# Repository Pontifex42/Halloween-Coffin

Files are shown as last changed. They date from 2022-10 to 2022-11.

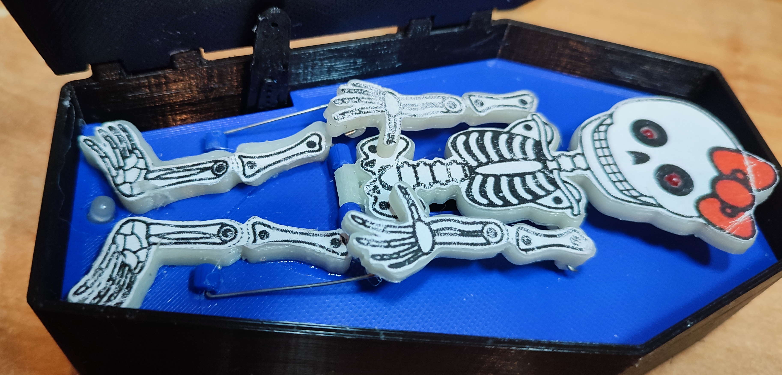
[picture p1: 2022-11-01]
Media/TopView.jpg

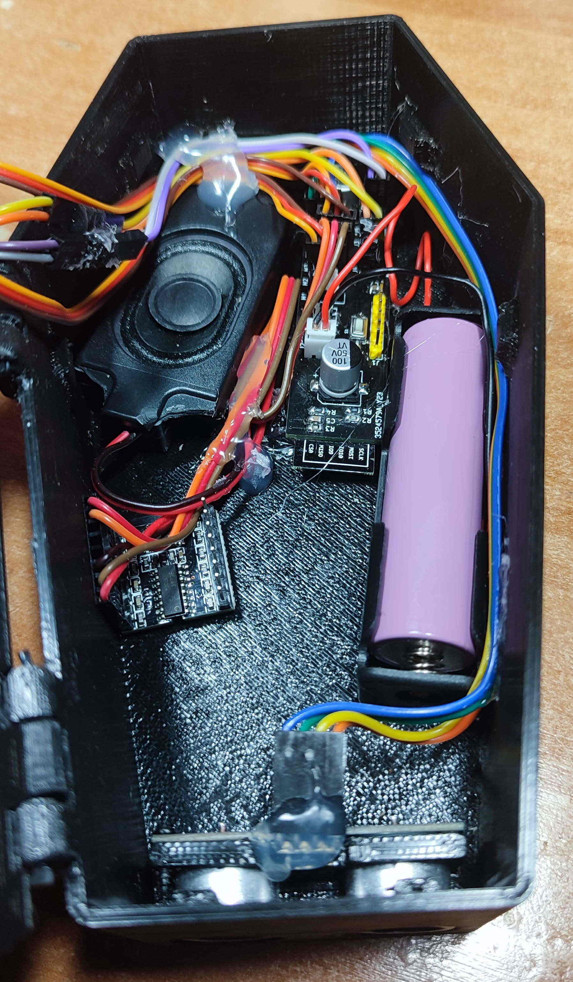
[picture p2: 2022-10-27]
Media/InnerView.jpg

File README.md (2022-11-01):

# Halloween-Coffin
A little scary toy.

Based on an idea from here:
https://www.az-delivery.de/blogs/azdelivery-blog-fur-arduino-und-raspberry-pi/halloween-2022-der-suessigkeitenwaechter

Software is based on a miniature board using ESP8266 which I developed myself.
Any other microcontroller would do, but my code might use some minor changes.
To make your own board, here are schematics and Gerber files:
https://github.com/Pontifex42/UniMiniESP8266
Not all components have to be populated, many parts are optional.

Some more information to build it is on thingiverse:
https://www.thingiverse.com/thing:5584885

Mp3 samples are for mp3 player like DFPlayer.
Some mp3 snippets are omitted due to legal reasons, I took them from a song "Nina Hagen - Auf'm Friedhof".
Feel free to place your own samples (< 10 seconds), the filename scheme is obvious.

Questions? Ideas? Contact github@hartwig.org. I answer all messages fast.

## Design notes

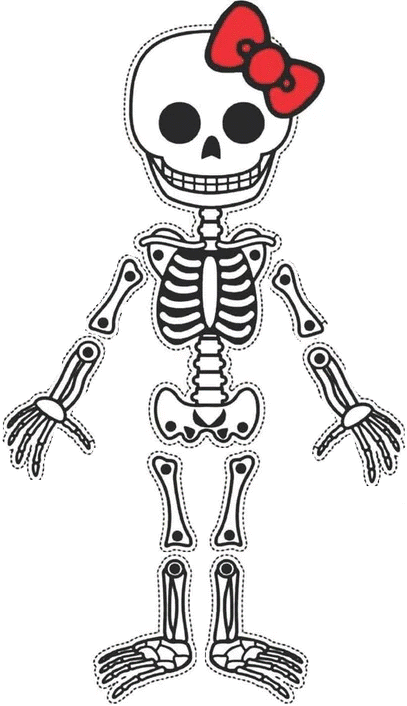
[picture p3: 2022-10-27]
Media/Skeleton_1024x1024.png

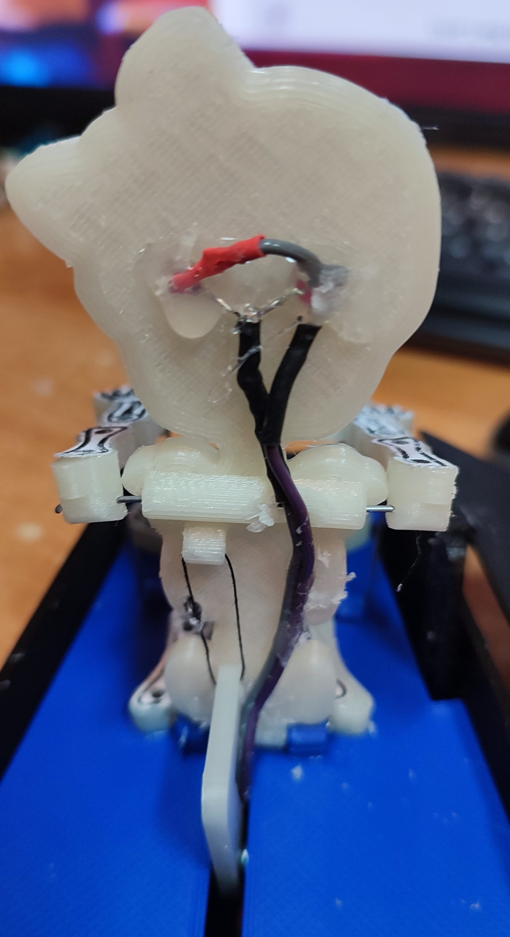
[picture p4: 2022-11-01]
Media/BackView.jpg

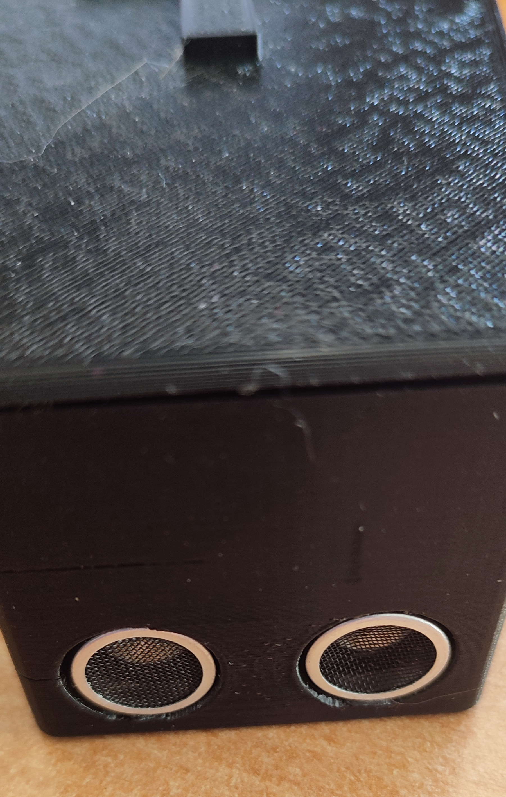
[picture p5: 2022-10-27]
Media/UltrasonicView.jpg

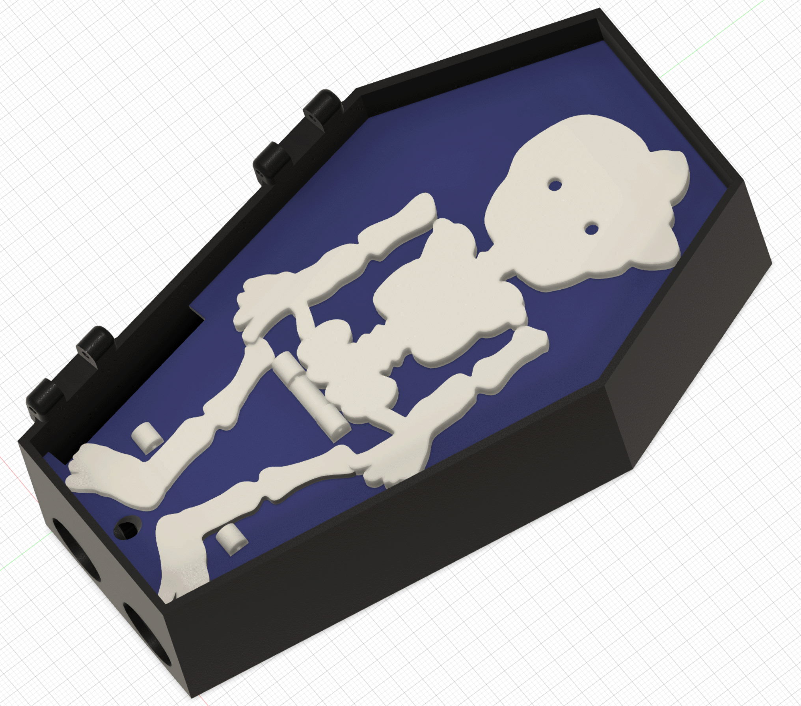
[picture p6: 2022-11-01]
Media/FusionView.jpg

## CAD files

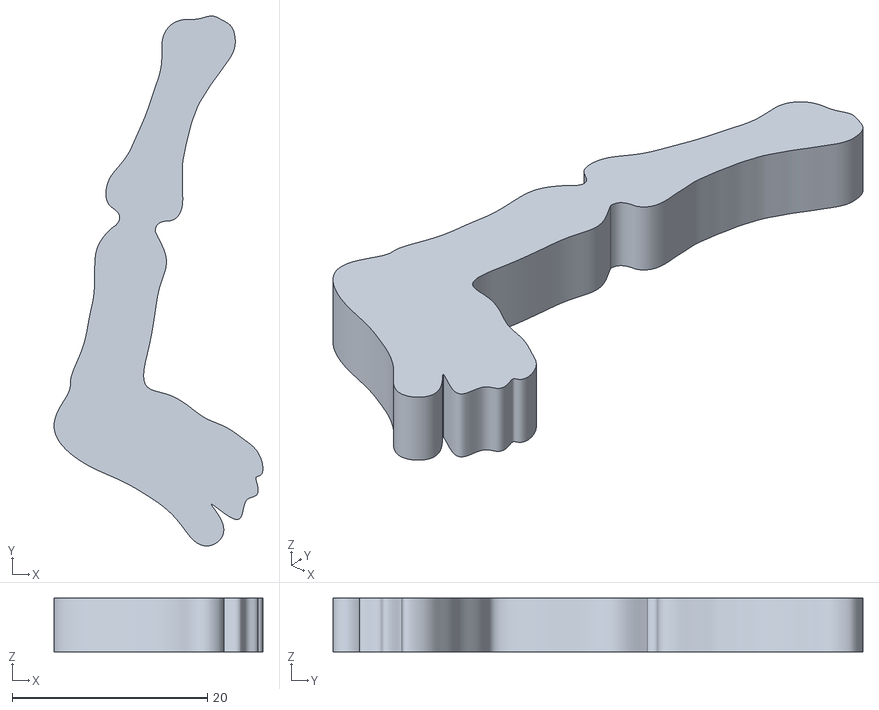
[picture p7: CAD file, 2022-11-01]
STL/Corpse Leg L.stl
21.4 x 54.3 x 5.50

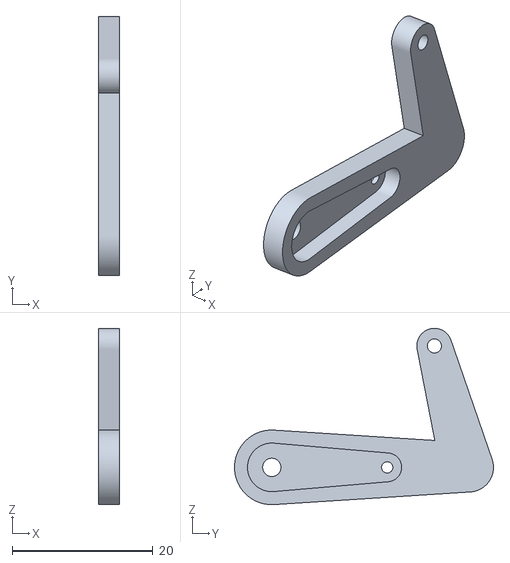
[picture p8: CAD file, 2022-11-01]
STL/Lever Short.stl
3.00 x 36.8 x 25.1

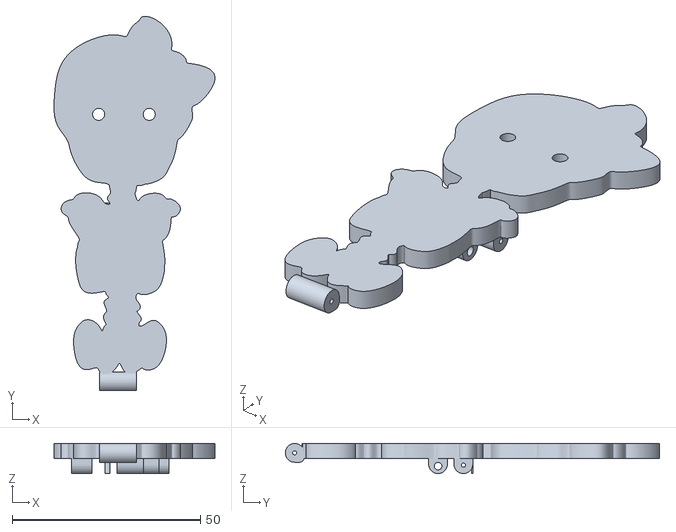
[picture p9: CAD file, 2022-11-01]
STL/Corpse Body.stl
42.7 x 99.4 x 8.00

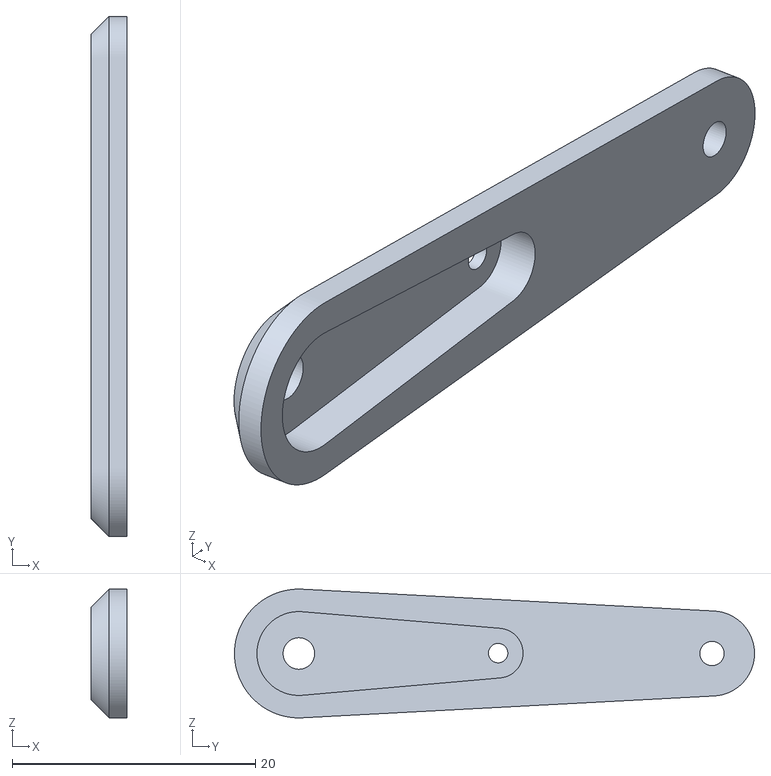
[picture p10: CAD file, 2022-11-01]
STL/Lever Long.stl
3.00 x 42.8 x 10.6

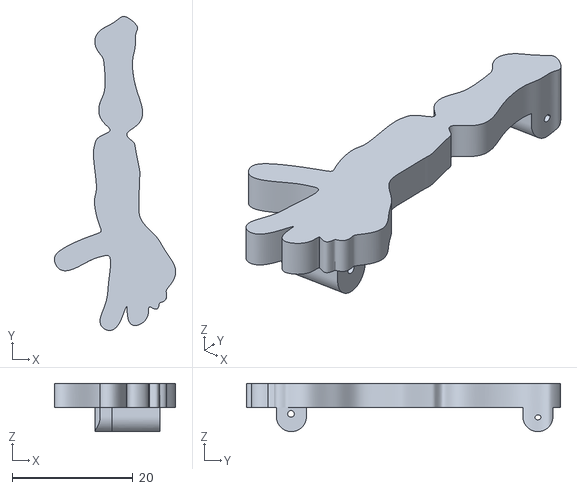
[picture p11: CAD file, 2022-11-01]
STL/Corpse Arm L.stl
20.1 x 52.1 x 8.00

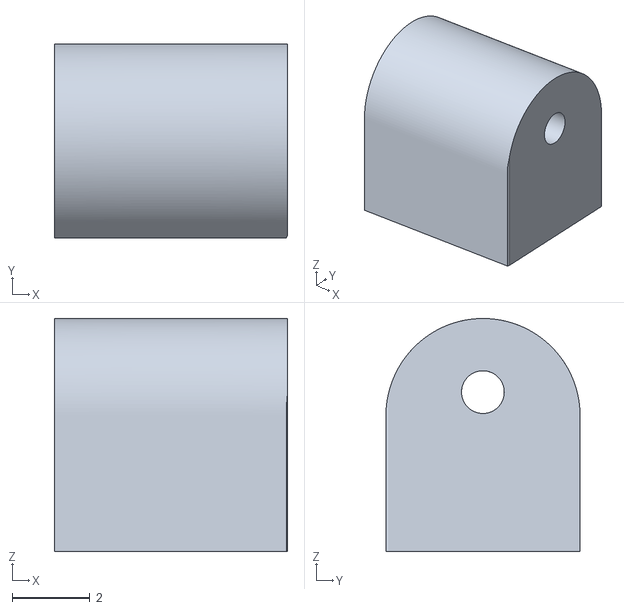
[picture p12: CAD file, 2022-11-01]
STL/Pelvis Hinge L.stl
6.00 x 5.00 x 6.00

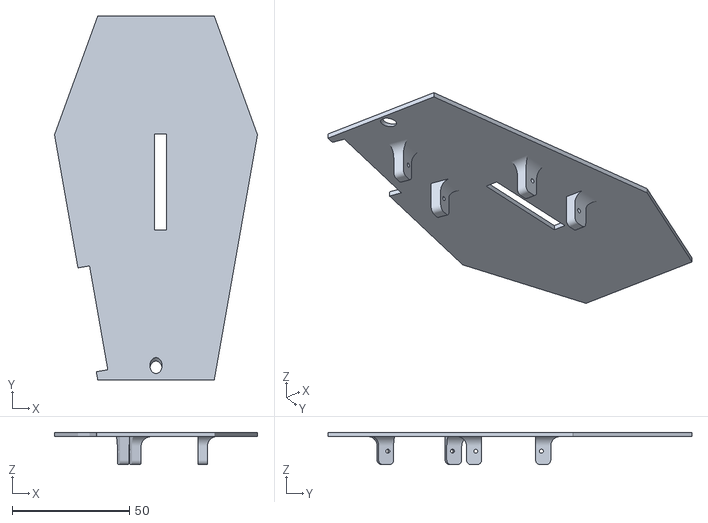
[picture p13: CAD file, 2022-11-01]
STL/InnerBoard.stl
86.6 x 155.2 x 13.8

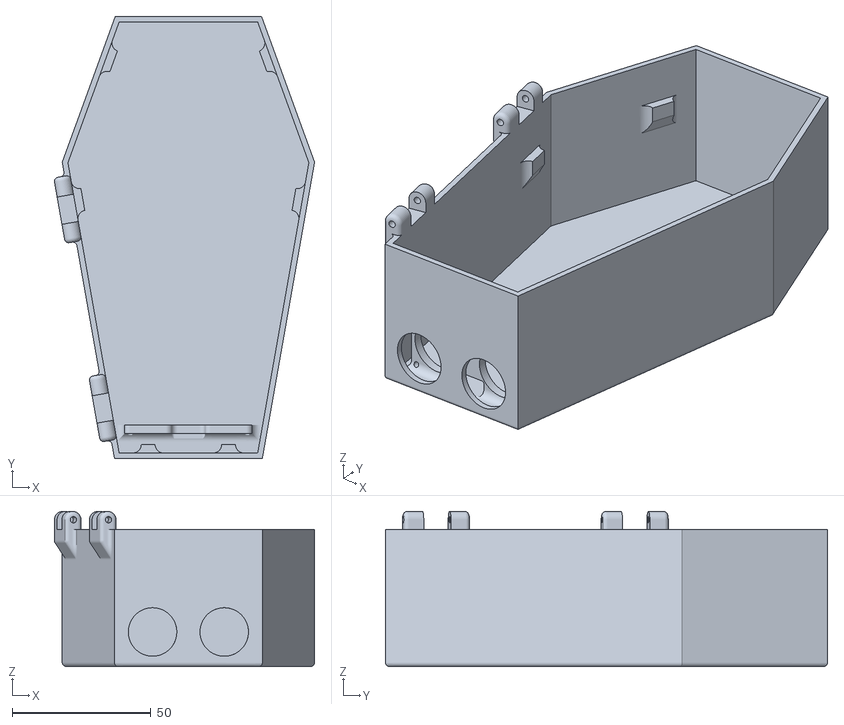
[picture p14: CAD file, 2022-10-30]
STL/Body.stl
93.9 x 159.5 x 56.0

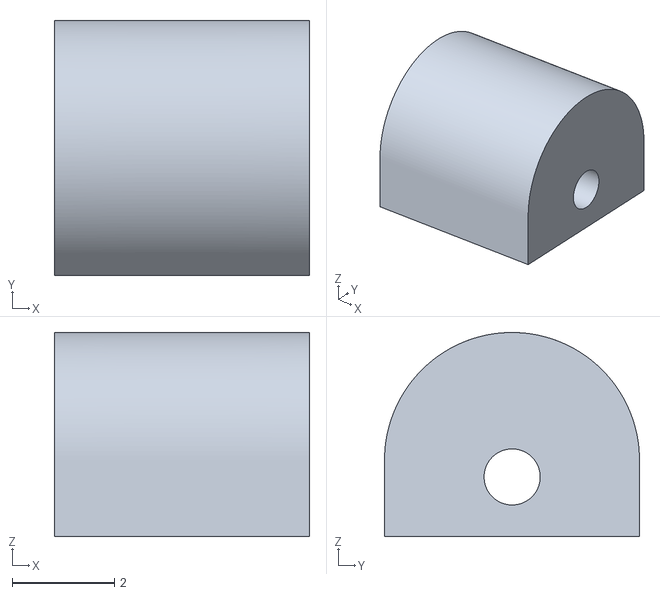
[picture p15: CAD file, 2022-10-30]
STL/Foot Hinge R.stl
5.00 x 5.00 x 4.00

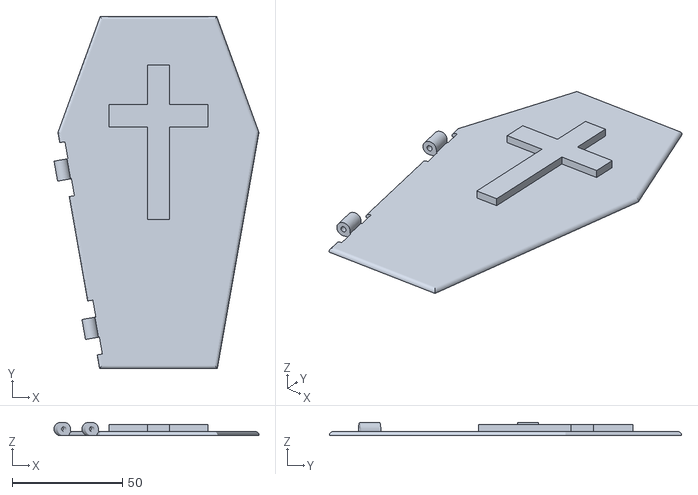
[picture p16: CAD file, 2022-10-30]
STL/Cover.stl
92.8 x 159.5 x 6.00

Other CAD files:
STL/Corpse Arm R.stl
STL/Pelvis Hinge R.stl
STL/Corpse Leg R.stl
STL/Foot Hinge L.stl
STL/Coffin.f3d

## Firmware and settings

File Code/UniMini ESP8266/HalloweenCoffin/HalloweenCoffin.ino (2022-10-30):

#include "PinConfig.h"
#include "BatteryProtect.h"
#include "CoffinServos.h"
#include "Ultrasonic.h"
#include "LEDs.h"
#include "Remote.h"
#include "CoffinMP3Player.h"

// #define DEBUG_INO
#ifndef DEBUG_INO
#undef DEBUG_PRINTLN
#undef DEBUG_PRINT
#define DEBUG_PRINTLN(a)
#define DEBUG_PRINT(a)
#endif

void SpecialDelay(double wait)
{
    unsigned long finish = millis() + wait;

    while (millis() < finish)
    {
        LoopServos();
        yield();
    }
}

void SpecialTone(int frequency, unsigned long duration = 0)
{
    tone(PIN_TONE, frequency, duration);
    LoopServos();
    yield();
}

void setup() 
{
    Serial.begin(115200);
    DEBUG_PRINTLN(""); // ESP sends garbage using 74880 baud at boot.
    DEBUG_PRINTLN("Halloween 2022");    // Serial monitor message

    SetupBatteryProtect();
    SetupServos();
    SetupUltrasonic();
    SetupLEDs();
    SetupRemote();
    SetupMP3Player();

    // After swiching on, give time to close cover and place the coffin
    delay(6000);
    CoffinPlayMP3(KICHERN);
    delay(6000);
    DEBUG_PRINTLN("Setup done");
}

#define DISTANCE_SLEEP 80
#define DISTANCE_ATTENTION 50
#define DISTANCE_ALARM 25
#define DISTANCE_HORROR 25

void loop() 
{
    LoopBatteryProtect();
    if (IsBatteryAlarmActive())
        return;

    LoopServos();

    LoopLEDs();

    LoopRemote();

    if (!AllServosFinished())
        return;

    LoopUltrasonic();
    
    LoopMP3Player();

    if (RemoteXYIsConnected())
    {
        DoRemoteControlledAction();
        return;
    }

    enum CoffinState
    {
        none, // only for boot
        sleep,
        attention,
        alarm,
        horror
    };
    static CoffinState currentState = none;
    if (distance >= DISTANCE_SLEEP)
    {
        if (currentState != sleep)
        {
            currentState = sleep;
            DEBUG_PRINTLN("Enter state: Sleep");
            SetEye(off);
            SetLight(false);
            CoverClose();
        }
    }
    else if (distance > DISTANCE_ATTENTION)
    {
        if (currentState != attention)
        {
            DEBUG_PRINTLN("Enter state: Attention");
            SetEye(off);
            SetLight(true);
            CoverClose();

            if ((currentState != horror) && (currentState != alarm)) // do not play music if target moves away
                CoffinPlayMP3(BRUELL);
            
            currentState = attention;
        }
    }
    else if (distance > DISTANCE_ALARM)
    {
        if (currentState != alarm)
        {
            currentState = alarm;
            DEBUG_PRINTLN("Enter state: Alarm");
            SetEye(glow);
            SetLight(true);
            CoverOpen();
            CorpseDown();
        }
    }
    else // if (distance <= DISTANCE_HORROR)
    {
        if (currentState != horror)
        {
            currentState = horror;
            DEBUG_PRINTLN("Enter state: Horror");
            CoffinPlayMP3(SCHREI);
            SetLight(true);
            SetEye(hypno);
            CorpseUp();
        }
    }
}

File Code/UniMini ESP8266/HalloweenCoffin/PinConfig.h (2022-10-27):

#pragma once
#include "Arduino.h"


#define PIN_M1 0	// Used for bootloader and Incremental-Switch, too. Is pulled up externally.
#define PIN_M2 2	// This is TXD ofer Serial1
#define PIN_M3 4 // Used for I2C
#define PIN_M4 5 // Used for I2C
#define PIN_M5 12
#define PIN_M6 13 // Re-used for PWM bin
#define PIN_MOT_A	14
#define PIN_MOT_B	15
#define PIN_SPARE	16
#define PIN_PWM PIN_M6

// Overdischarge protection
#define PIN_CHECK_BATT	A0


#define PIN_LED_EYES			PIN_SPARE
#define PIN_LED_WHITE_A			PIN_MOT_A // Ensure other motor pin is held low
#define PIN_LED_WHITE_B			PIN_MOT_B
#define PIN_TONE				PIN_PWM 

// HC-SR04 ultrasonic sensor
#define PIN_ULTRASONIC_TRIGGER	PIN_M5 // (Yellow wire)
#define PIN_ULTRASONIC_ECHO		PIN_M4 // (Green wire)

#define PIN_SERVO_COVER			PIN_M3
#define PIN_SERVO_CORPSE		PIN_M1

#define DEBUG_PRINTLN(a) Serial.println(a)
#define DEBUG_PRINT(a) Serial.print(a)

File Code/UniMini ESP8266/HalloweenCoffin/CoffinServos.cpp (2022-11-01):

#include "CoffinServos.h"
#include "PinConfig.h"
#include "CoffinMP3Player.h"

//#define DEBUG_COFFINSERVOS

#ifndef DEBUG_COFFINSERVOS
#undef DEBUG_PRINTLN
#undef DEBUG_PRINT
#define DEBUG_PRINTLN(a)
#define DEBUG_PRINT(a)
#endif

#define MIN_COVER 500
#define MAX_COVER 2500

#define MIN_CORPSE 500
#define MAX_CORPSE 2500

#define PWM_CORPSE_DOWN 2200
#define PWM_CORPSE_UP 880

#define PWM_COVER_OPEN 2100
#define PWM_ARM_TOUCHES_COVER 1350
#define PWM_COVER_CLOSED 1380

CoffinServo ServoCover(PIN_SERVO_COVER, MIN_COVER, MAX_COVER);
CoffinServo ServoCorpse(PIN_SERVO_CORPSE, MIN_CORPSE, MAX_CORPSE);

CoffinServo::CoffinServo(int pin, int min, int max)
{
	myPin = pin;
	myMin = min; // it is allowed that min is greater than max
	myMax = max;
	myPWM = (myMin + myMax) / 2;

	SmoothMode = false;
	TargetPWM = myPWM;
	increment = 0;
	PWMperStep = 0.0;
	TimeOfNextStep = millis();
}

void CoffinServo::Setup()
{
	RestartServo();
}

void CoffinServo::ShutdownServo()
{
	myServo.detach();
}

void CoffinServo::RestartServo()
{
	if (myMin < myMax)
		myServo.attach(myPin, myMin, myMax, myPWM);
	else
		myServo.attach(myPin, myMax, myMin, myPWM);
}

void CoffinServo::MoveTo(int pwm)
{
	if (pwm == myPWM)
		return;

	if (myMin < myMax)
	{
		if (pwm < myMin)
			pwm = myMin;
		else if (pwm > myMax)
			pwm = myMax;
	}
	else // (myMin > myMax)
	{
		if (pwm > myMin)
			pwm = myMin;
		else if (pwm < myMax)
			pwm = myMax;
	}

	myServo.writeMicroseconds(pwm);
	myPWM = pwm;
}

#define STEPTIME 20.0 // 50Hz servos take one setting every 20ms
void CoffinServo::MoveSmoothTo(int pwm, long time)
{
	DEBUG_PRINTLN("MoveSmoothTo " + String(pwm));
	if (myMin < myMax)
	{
		if (pwm < myMin)
			pwm = myMin;
		else if (pwm > myMax)
			pwm = myMax;
	}
	else // (myMin > myMax)
	{
		if (pwm > myMin)
			pwm = myMin;
		else if (pwm < myMax)
			pwm = myMax;
	}

	StartPWM = myPWM;
	TargetPWM = pwm;

	if (StartPWM == TargetPWM)
		return;

	if (time < STEPTIME)
		time = STEPTIME;

	double steps = double(time) / STEPTIME;
	PWMperStep = (TargetPWM - StartPWM) / steps;

	increment = 0;
	SmoothMode = true;
	TimeOfNextStep = millis();
	MakeSmoothStep();
}

void CoffinServo::MakeSmoothStep()
{
	if (TargetPWM == myPWM)
		return;

	increment++;
	int nextPWM = StartPWM + (PWMperStep * increment);
	if (PWMperStep > 0)
	{
		if (nextPWM > TargetPWM)
			nextPWM = TargetPWM;
	}
	else
	{
		if (nextPWM < TargetPWM)
			nextPWM = TargetPWM;
	}
	DEBUG_PRINTLN("Step: " + String(nextPWM));
	MoveTo(nextPWM);
	TimeOfNextStep += STEPTIME;
}

enum MovePending
{
	pending_none,
	pending_CorpseUp,
	pending_CoverClose

}MovePending;

void CoffinServo::Loop()
{
	if (!SmoothMode)
		return;

	if (millis() < TimeOfNextStep)
		return;

	if (TargetPWM == myPWM)
	{
		SmoothMode = false;
		DEBUG_PRINTLN("Smooth move done");
		if (MovePending == pending_CorpseUp)
		{
			MovePending = pending_none;
			CorpseUp();
		}
		else if (MovePending == pending_CoverClose)
		{
			MovePending = pending_none;
			CoverClose();
		}

		return;
	}

	MakeSmoothStep();
}

// -------------------------------------------------------

void SetupServos()
{
	ServoCover.Setup();
	ServoCover.MoveTo(PWM_COVER_CLOSED);
	ServoCorpse.Setup();
	ServoCorpse.MoveTo(PWM_CORPSE_DOWN);
}

void LoopServos()
{
	ServoCover.Loop();
	ServoCorpse.Loop();
}

bool  AllServosFinished()
{
	return ServoCover.IsMoveFinished() && ServoCorpse.IsMoveFinished();
}

void ShutdownAllServos()
{
	ServoCover.ShutdownServo();
	ServoCorpse.ShutdownServo();
}

void RestartAllServos()
{
	ServoCover.RestartServo();
	ServoCorpse.RestartServo();
}

#define TIME_TO_CLOSE 4500
#define TIME_TO_OPEN 6500

#define TIME_TO_RAISE 3500
#define TIME_TO_LAYDOWN 3000

void PlayCorpseUpDownSound()
{
	const int CorpsUpSoundSelection[] =
	{
		WANTYOUTODIE,
		TODESSCHREI,
		SCHREI,
		BRUELL,
		BRUELL2,
		GESPENST,
		GLOCKENSCHLAG,
		KICHERN,
		KRAEHE,
		MEINGERIPPE,
		WOLF1
	};

	int r = random(11);

	CoffinPlayMP3(CorpsUpSoundSelection[r]);
	DEBUG_PRINTLN("Corpse sound: " + String(no));
}


void CorpseUp()
{
	CoverOpen();
	if (!AllServosFinished())
	{
		MovePending = pending_CorpseUp;
		return;
	}
	if (ServoCorpse.GetPWM() == PWM_CORPSE_DOWN)
		PlayCorpseUpDownSound();

	ServoCorpse.MoveSmoothTo(PWM_CORPSE_UP, TIME_TO_RAISE);
}

void CorpseDown()
{
	if (ServoCorpse.GetPWM() == PWM_CORPSE_UP)
		PlayCorpseUpDownSound();

	ServoCorpse.MoveSmoothTo(PWM_CORPSE_DOWN, TIME_TO_LAYDOWN);
}

void CoverOpen()
{
	if (ServoCover.GetPWM() == PWM_COVER_CLOSED)
		CoffinPlayMP3(KNARREN);

	ServoCover.MoveSmoothTo(PWM_COVER_OPEN, TIME_TO_OPEN);
}

void CoverClose()
{
	CorpseDown();
	if (!AllServosFinished())
	{
		MovePending = pending_CoverClose;
		return;
	}

	if (ServoCover.GetPWM() == PWM_COVER_OPEN)
		CoffinPlayMP3(KNARREN2);

	ServoCover.MoveSmoothTo(PWM_COVER_CLOSED, TIME_TO_CLOSE);
}

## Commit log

2022-10-27 Decent working version
    [Body.stl, Coffin.f3d, Corpse Arm L.stl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]
2022-10-30 Some minor improvements for 3D print, added some sounds and play the randomly.
    [Body.stl, Coffin.f3d, Corpse Arm L.stl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]
2022-11-01 Modifications for a better arm movement
    [Coffin.f3d, Corpse Arm L.stl, Corpse Arm R.stl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]
